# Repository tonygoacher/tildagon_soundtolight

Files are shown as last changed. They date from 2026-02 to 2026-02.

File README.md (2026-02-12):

# TGSTL

TGSTL is a micropython application to run on the [EMF camp](https://www.emfcamp.org/) Tildagon badge as
a sound to light display using the onboard LEDs. Please note you'll need to do a bit of
soldering to get this going!! The sound detector board was designed to run of 5V so we'll need to change a resistor 
value on the PCB.

The code is a C to micropython port by Tony Goacher from 

This code ported from Michael Bartlett's C code for the Sparkfun LED visualizer (https://github.com/sparkfun/SparkFun-RGB-LED-Music-Sound-Visualizer-Arduino-Code)
to micro python by Tony Goacher (https://github.com/tonygoacher/tildagon_soundtolight)
Licence as orginal below.

Please see **instructions.pdf** for contruction details.

## License

Creative Commons Attribution-ShareAlike 4.0 (CC BY-SA 4.0)

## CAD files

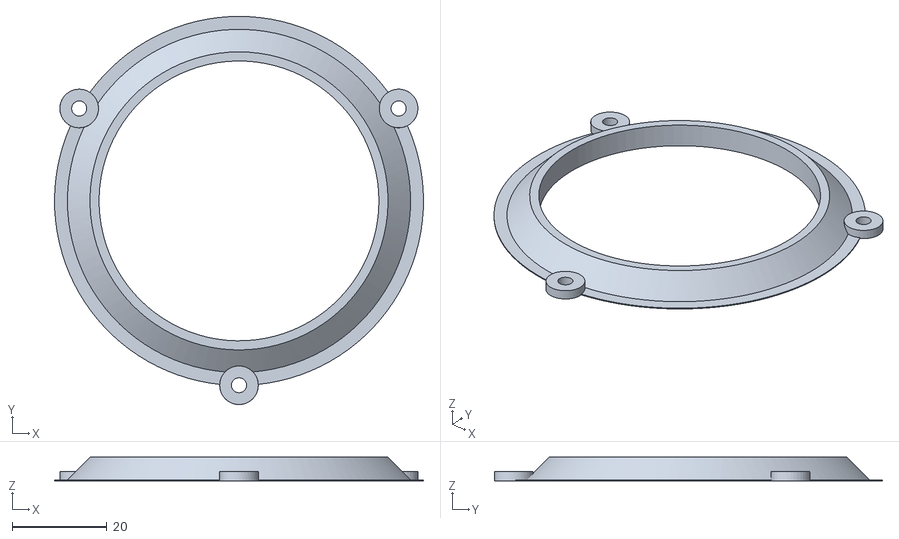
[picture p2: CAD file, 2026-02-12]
hardware/LEDEnhancer.stl
78.0 x 82.1 x 5.00

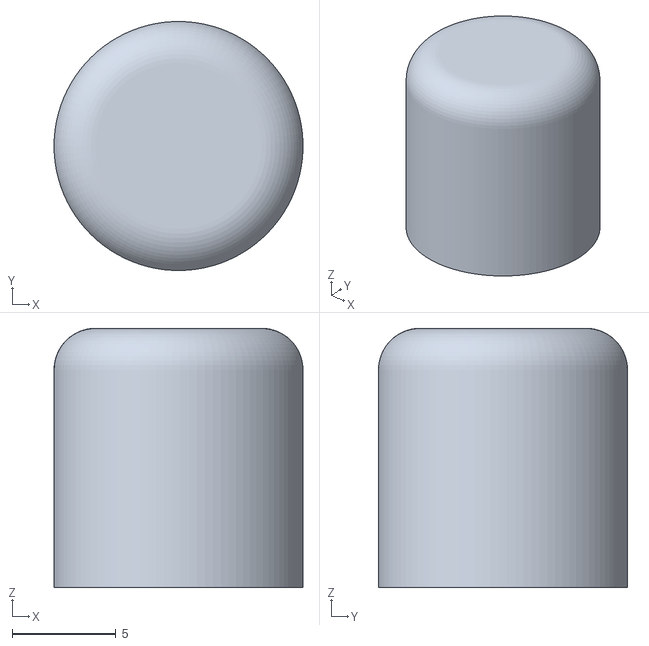
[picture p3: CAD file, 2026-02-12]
hardware/PotKnob.stl
12.0 x 12.0 x 12.5

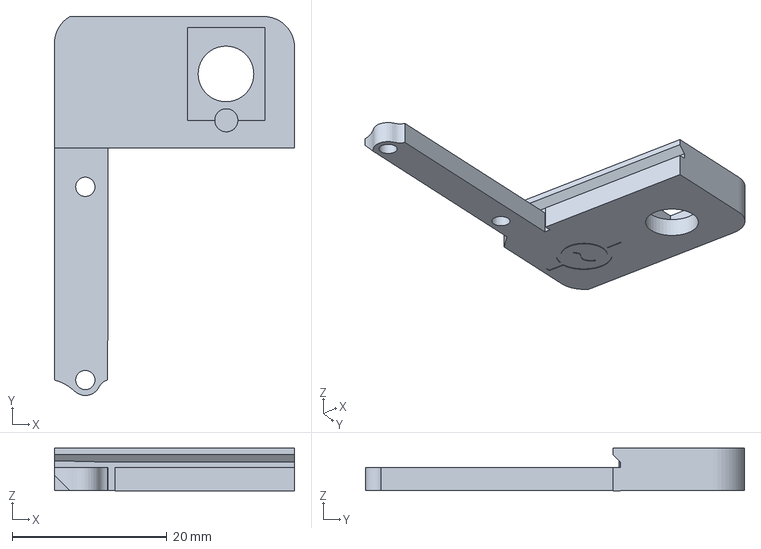
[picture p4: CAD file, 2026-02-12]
hardware/POTMount.3mf
31.1 x 49.0 x 5.52 mm

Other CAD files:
hardware/POTMount.stl

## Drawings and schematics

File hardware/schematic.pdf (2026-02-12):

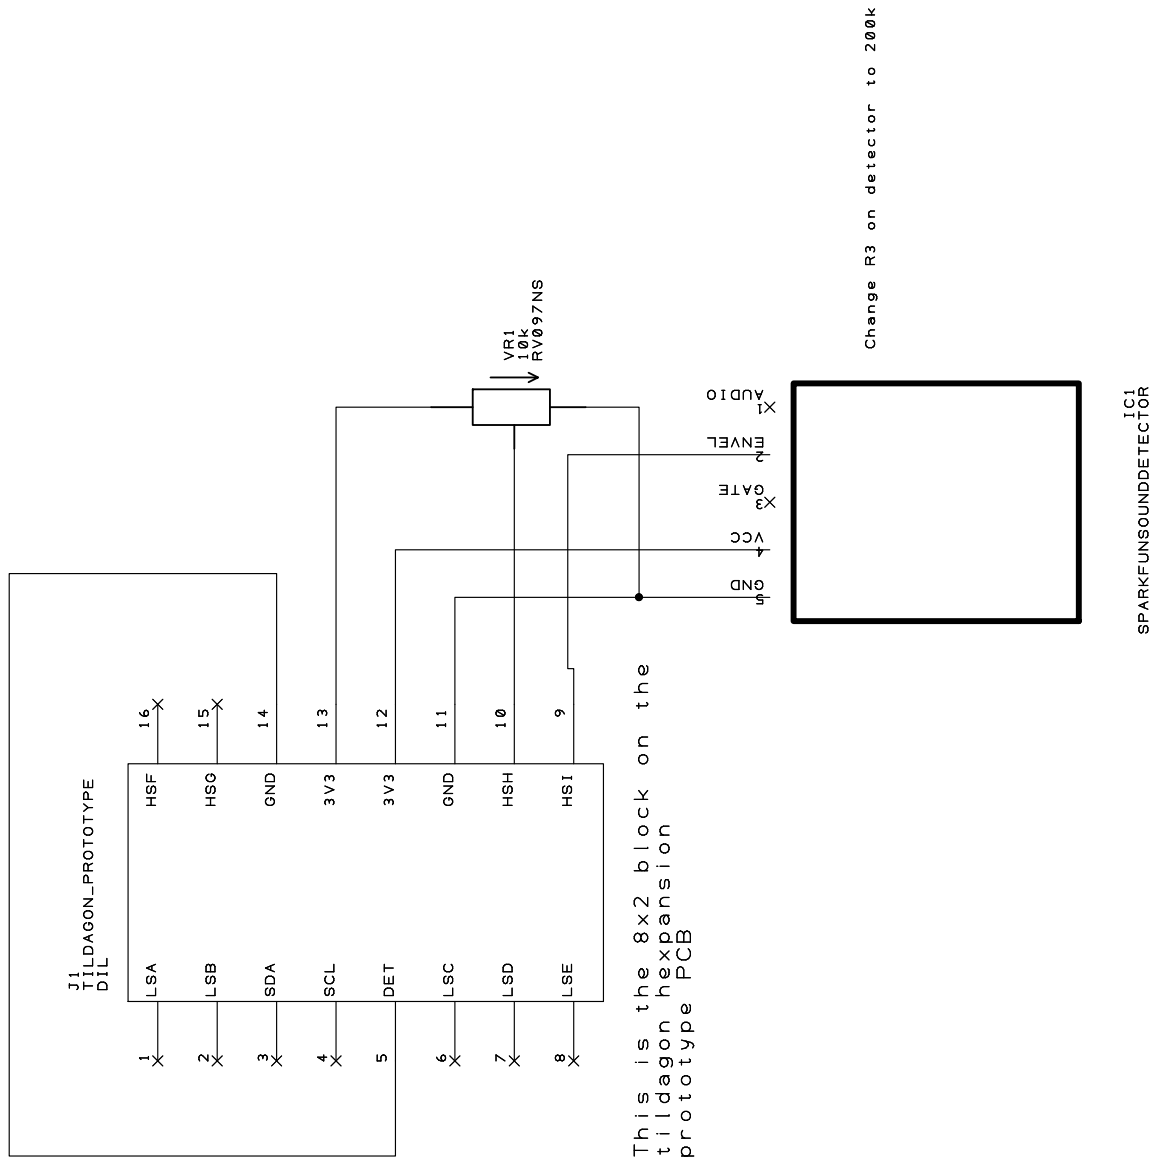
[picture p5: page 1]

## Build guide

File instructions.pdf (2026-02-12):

## TGSTL: Tildagon sound to light Hexpansion for EMF Camp tildagon badge

What is it
TGSTL uses a third-party sound detector board to produce cool sound to light effects on the EMF camp Tildagon badge LEDs. It uses a 3D printed LED enhancer to provide a much larger reflective surface for the badge LEDs.

There is a video of it in action at:
https://youtu.be/Oy822CMz1iM

What do I need to make it work
Protohex Hexpansion PCB by Jake Walker https://www.tindie.com/products/jakew/protoboard-hexpansion/

Sparkfun sound detector with header https://thepihut.com/products/sparkfun-sound-detector-with-headers

RV097NS style 10k ohm potentiometer https://www.amazon.co.uk/dp/B07SVLZNYP
Software at https://github.com/tonygoacher/tildagon_soundtolight
2 x M2 x 8mm screws.
2 x M2 washers.

There are a few 3D printed parts too:

Potentiometer mount

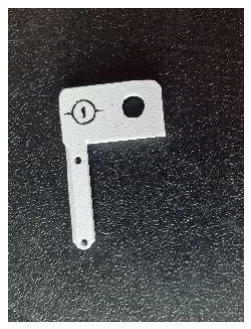
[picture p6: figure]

LED enhancer (make sure this is printed in white material!)

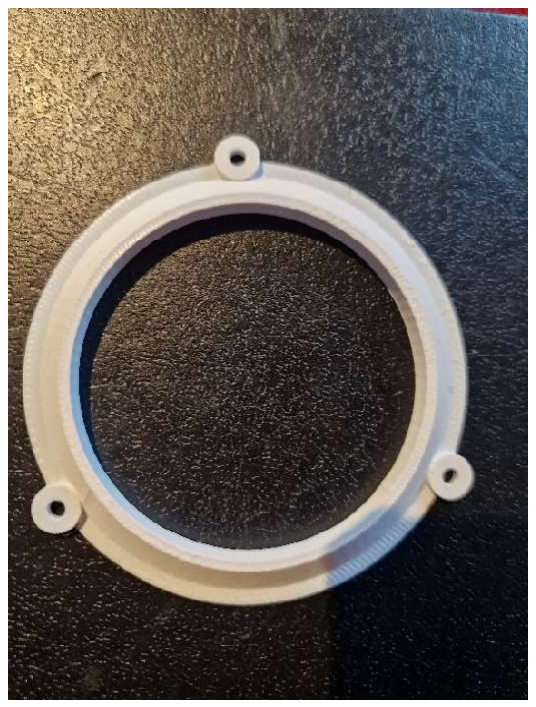
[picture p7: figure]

Potentiometer knob

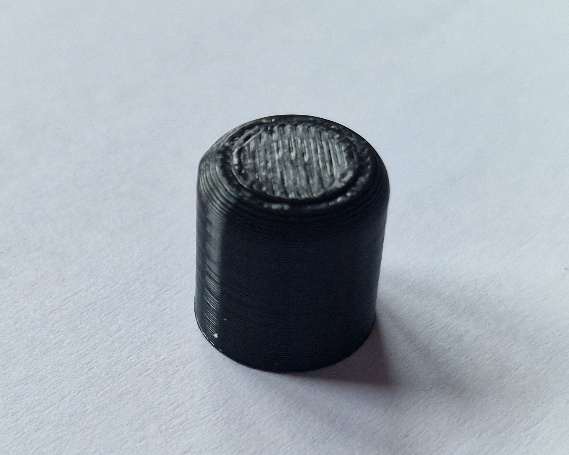
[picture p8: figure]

How to make it
1. Change the Sound Detector resistor R3 for a value of 200k ohms.

### 2. Solder the sound detector board to the TOP of the Protohex board in

the position shown. The picture on the next page shows the sound detector PCB pins highlighted in green on the bottom of the protohex board.

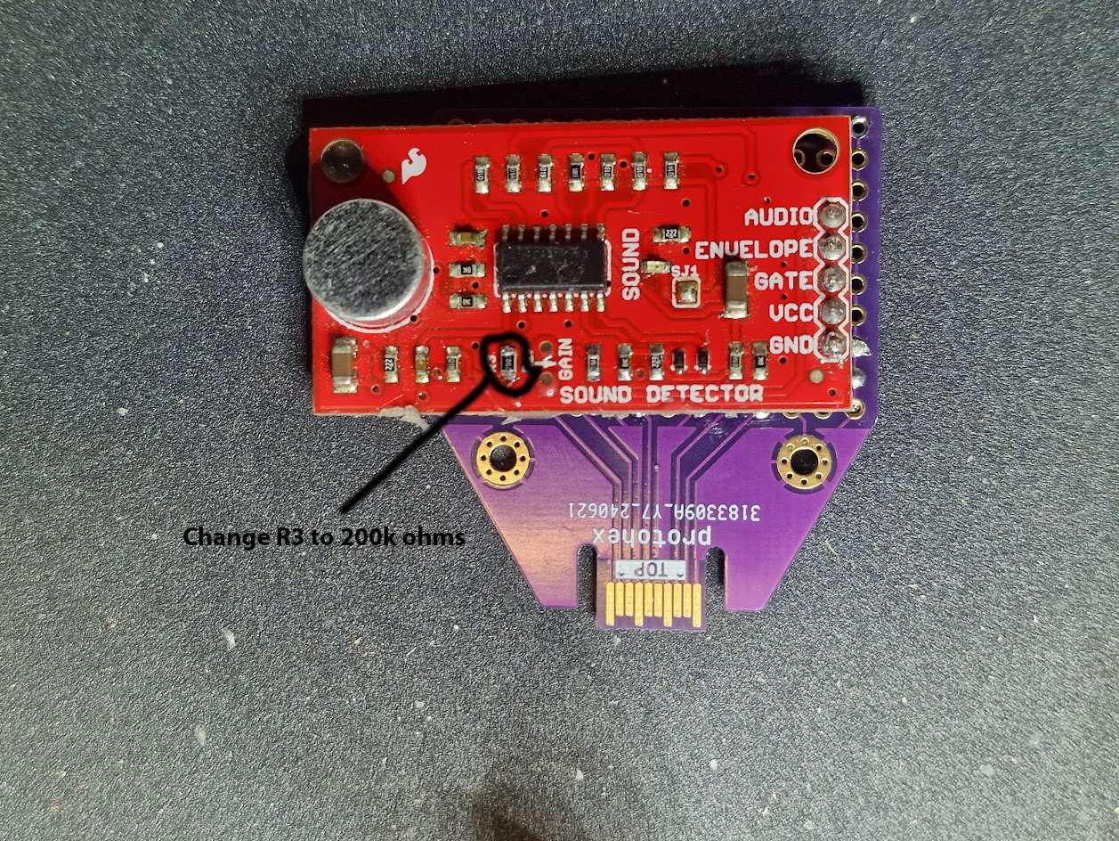
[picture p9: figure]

### 3. Wire up the board as shown. Note the small GND wire connecting the

bottom pin of the sound board to the GND bus

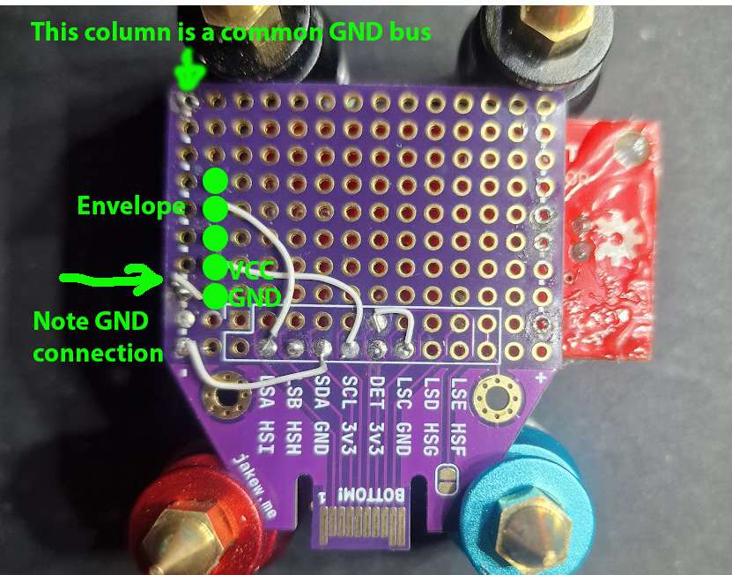
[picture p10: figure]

Ensure the sound detector board is connected in the position shown by the green circles.
Ensure that the left side column of holes is clear. These holes are connected together on the PCB (indicated by the small white lines on the PCB) and are used as a common GND bus.

The Hexpansion protoboard connections:
DET | GND
3V3 | Sparkfun VCC
3V3 | Potentiometer A
GND | Potentiometer B
GND | Sparkfun GND
HSH | Potentiometer Wiper (centre pin)
HSI | Sparkfun Envelope

Now fit the potentiometer to the mount and wire as shown.

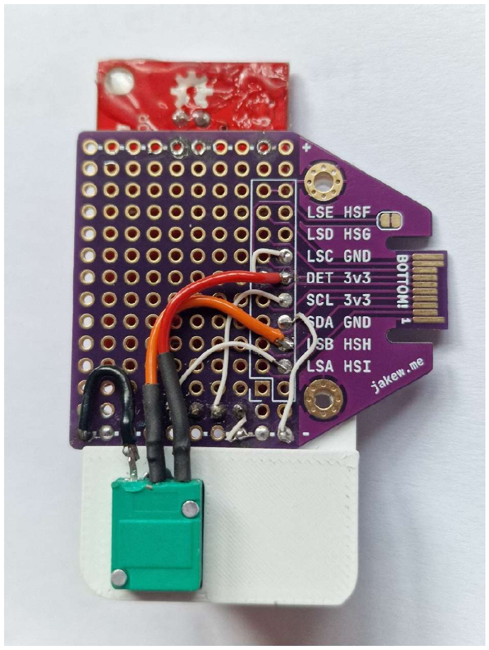
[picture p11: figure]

Fitting
Unscrew the 3 M3 screws holding the badge top PCB in place.
Plug the Hexpansion into port 4
Fit the M2 screws.
Place the LED enhancer onto the badge top PCB and re-fit the M3 screws.

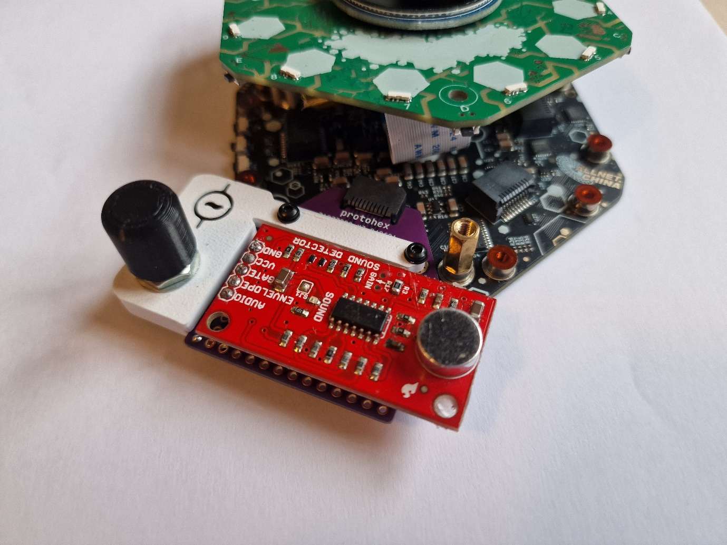
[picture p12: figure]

Deploying the software
You will need to ensure git and mpremote are installed on your computer. There is a great tutorial here:
https://tildagon.badge.emfcamp.org/using-the-badge/connect-to-wifi/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

Download the TGSTL software from the github repo: https://github.com/tonygoacher/tildagon_soundtolight
Using a command line interface, navigate to the software folder. Connect the tildagon badge USB in port to your computer
If you have a bash shell, simply run ‘deploy.sh’.

Without a bash shell, run the following commands mpremote mkdir apps
mpremote mkdir apps tgstl
mpremote fs cp app.py :/apps/tgstl/
mpremote fs cp metadata.json :/apps/tgstl/ mpremote fs cp tildagon.toml :/apps/tgstl/ mpremote fs cp logo.jpg :/apps/tgstl/

When finished. Press the ‘reboop’ button.

Using TGSTL
Power on the tildagon badge using the ‘bat’ button.

The blue led on Hexpansion port 4 should illuminate to indicate the Hexpansion has been detected.
TGSTL should appear on the system menu, scroll through menu using the ‘A’ and ‘D’ buttons. Activate the app with the ‘C’ button.
Press and hold the ‘A’ button to change effects. As the python script runs in a tight loop, it may take up to 1 second for the first press to be detected. Subsequent button press should run at normal speed.
The current effect is displayed in the text box on the LCD display.
Use the potentiometer to adjust the sensitivity. Setting sensitivity to minimum automatically causes the default ‘Rainbow’, none sound activated, effect to run.

Press and hold the ‘F’ key to quit the app.
NOTE: The script runs in a 20ms loop and does not return control to the tildagon OS as frequently as a normal app. This will probably break other apps running at the same time. This is because the default 50ms update time of a normal app is too slow to detect the sound envelopes used to create the effects.
Have Fun!!
Tony
Instagram: tonygoacher
Youtube: https://www.youtube.com/TonyGoacher

If you want some help desoldering the resistor (you send me the board, I’ll do it for you if you!) , printing the parts or in general with this project. Just email me at:

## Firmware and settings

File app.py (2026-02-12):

import app
import simple_tildagon as st
from system.eventbus import eventbus
from tildagonos import tildagonos, led_colours
from system.eventbus import eventbus
from system.patterndisplay.events import *

from events.input import Buttons, BUTTON_TYPES, ButtonDownEvent
from system.hexpansion.config import *
from machine import Pin, ADC
import time
import random
import asyncio
import math
import sys
import os

# EMF Camp Tilda badge sound to light application

# This application uses the Sparkfun sound detector board (https://www.sparkfun.com/sparkfun-sound-detector.html)
# to produce a half-decent sound to light display on the EMF camp (https://www.emfcamp.org/) 
# Tildagon badge (https://tildagon.badge.emfcamp.org/) LEDs
#
# This code ported to Python from C for the Sparkfun LED visualizer (https://github.com/sparkfun/SparkFun-RGB-LED-Music-Sound-Visualizer-Arduino-Code)
# code by Michael Bartlett. Ported Tony Goacher (https://github.com/tonygoacher/tildagon_soundtolight)
# Licence as orginal below.
# I'm a C/C++ guy with no Python experience so please forgive my SNAFUs below!

# SparkFun Addressable RGB LED Sound and Music Visualizer Tutorial Arduino Code
# by: Michael Bartlett
# SparkFun Electronics
# date: 2/7/16
# license: Creative Commons Attribution-ShareAlike 4.0 (CC BY-SA 4.0)
# Do whatever you'd like with this code, use it for any purpose.
# Please attribute and keep this license.



if sys.implementation.name == "micropython":
    apps = os.listdir("/apps")
    path = ""
    for a in apps:
        # This is important for apps deployed to the appstore
        # The Snake app from naomi stored at
        # https://github.com/npentrel/tildagon-snake/
        # has all its files in the folder
        # npentrel_tildagon_snake
        if a == "github_user_github_repo_name":
            path = "/apps/" + a
    ASSET_PATH = path + "/assets/"
else:
    # while testing, put your files in the folder you are developing in,
    # for example: example/streak.jpg
    ASSET_PATH = "apps/example/"
    
    
print("Asset path", ASSET_PATH)    

NUM_LEDS = 12
LED_HALF = int(NUM_LEDS / 2)
VISUALS = 6     # The number of different visual effects
hexpansion_configa = None
audioIn = None
effectName = ""
#########################################################################################
def absint(i):
    i = int(i)
    if i < 0:
        i += 2**32            
    return i     
###########################################################################

class Strip():


    ledCache = [(0,0,0)for y in range(NUM_LEDS)] 
        
       
    def getColorAsNumber(self,led):
        led = int(led)
        if absint(led) >= NUM_LEDS:
            return 0
        
        col = list(self.ledCache[led])
        return self.createColourAsNumber(col[0], col[1], col[2])
    
    def setColourByNumber(self,led, colourValue):   # Set colour as number RRGGBB for led 0-nn
        if absint(led) >= NUM_LEDS:
            return
        
        colour = ((colourValue & 0xff0000) >> 16, (colourValue & 0xff00)>> 8 , colourValue & 0xff)
        self.ledCache[led] = colour

    def setPixelColour(self,led, r,g,b):   
        led = int(led)   
        if absint(led) >= NUM_LEDS:
            return
        
        #print("R:", absint(r) ,"G", absint(g), "B",absint(b))
        self.ledCache[led] = (absint(r),absint(g),absint(b))
        
    def createColourAsNumber(self,r,g,b):
        return (absint(r) * 0x010000) + (absint(g) * 0x0100) + absint(b)
    
    def deployLeds(self):
        for i in range( NUM_LEDS):
            st.led.set(i+1, self.ledCache[i])


    
theLedStrip = Strip()

HSH = 2
HSI = 3
LOOP_LEDS = NUM_LEDS + 1
DEFAULT_PORT = 4
ADJUST_PIN  = HSH      
AUDIO_IN_PIN = HSI  
KNOB_RAINBOW_ENABLE = 0.02   

audioIn = None
hexpansion_config = HexpansionConfig(DEFAULT_PORT)  # Due to A/D use we are limited what hexpansion we can use
audioIn = ADC(Pin(hexpansion_config.pin[AUDIO_IN_PIN]))
print("Using ADC pin ",hexpansion_config.pin[AUDIO_IN_PIN], "for audio in" )

knobAnalogueIn = ADC(Pin(hexpansion_config.pin[ADJUST_PIN]))

audioIn.atten(ADC.ATTN_11DB)
knobAnalogueIn.atten(ADC.ATTN_11DB)



thresholds = [1529, 1019, 764, 764, 764, 1274]

palette = 0  #Holds the current color palette.
visual = 0   #Holds the current visual being displayed.
volume = 0   #Holds the volume level read from the sound detector.
last = 0     #Holds the value of volume from the previous loop() pass.

maxVol = 15    #Holds the largest volume recorded thus far to proportionally adjust the visual's responsiveness.
knob = 1023.0  #Holds the percentage of how twisted the trimpot is. Used for adjusting the max brightness.
avgBump = 0    #Holds the "average" volume-change to trigger a "bump."
avgVol = 0     #Holds the "average" volume-level to proportionally adjust the visual experience.
shuffleTime = 0  #Holds how many seconds of runtime ago the last shuffle was (if shuffle mode is on).
shuffle = False
bump = False
gradient = 0

dotPos = 0  #Holds which LED in the strand the dot is positioned at. Recycled in most other visuals.
timeBump = 0 #Holds the time (in runtime seconds) the last "bump" occurred.
avgTime = 0
left = False

returnNow = 10   # Used to force the main loop to return for n iterations after a switch change
                # to allow time for another switch press/LCD update

pos = [-2] * NUM_LEDS


rgb = [[0 for x in range(3)] for y in range(NUM_LEDS)] 


####################################################################################

def map( x,  in_min,  in_max,  out_min,  out_max):
  return int((x - in_min) * (out_max - out_min) / (in_max - in_min) + out_min)

######################################################################################
def getADValue():
    advalue = audioIn.read_u16()
 
    return map(advalue, 0, 10500, 0,1023)

#########################################################################################
def millis():
    return time.ticks_ms()

#########################################################################################

def Wheel(WheelPos):
    WheelPos = 63 - WheelPos
    if WheelPos < 21:
        return theLedStrip.createColourAsNumber(63 - WheelPos * 3, 0, WheelPos * 3)

    if WheelPos < 42:
        WheelPos -= 21
        return theLedStrip.createColourAsNumber(0, WheelPos * 3, 63 - WheelPos * 3)
  
    WheelPos -= 42
    return theLedStrip.createColourAsNumber(WheelPos * 3, 63 - WheelPos * 3, 0)


##########################################################################################



#########################################################################################


def split(color, i ):

    #0 = Red, 1 = Green, 2 = Blue

    if i == 0:
        return (color & 0xff0000) >> 16
    if i == 1:
        return (color & 0x00ff00) >> 8
    if i == 2:
        return (color & 0xff) 
    print("Split invalid index ", i)
    return -1


#########################################################################################
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

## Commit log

2026-02-08 Implemented LED cache
2026-02-08 Added switch A now changes effect. Added mode feedbak on display
2026-02-10 Visual changer switch now more responsive after first delay
2026-02-10 Added logo. Changed current effect text colur and size
2026-02-12 Added hardware, readme and instructions.pdf
    [LEDEnhancer.stl, POTMount.3mf, POTMount.stl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]
